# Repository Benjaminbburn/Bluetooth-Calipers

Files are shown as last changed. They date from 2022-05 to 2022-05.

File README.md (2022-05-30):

# Bluetooth-Calipers

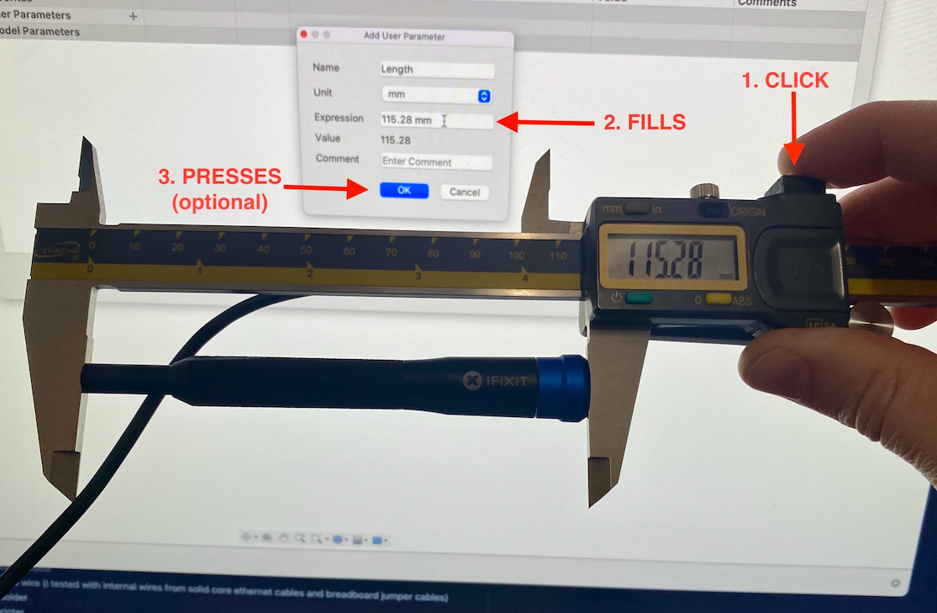
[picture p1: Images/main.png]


### Sends caliper data to connected bluetooth device when button is pressed.

---

The goal of this project was to recreate the functionality of [Mitutoyo's bluetooth U-WAVE](https://www2.mitutoyo.co.jp/eng/products/keisokusystem/wireless.html) using inexpensive hardware (total cost, excluding calipers, ~$15).

I ended up using USB for power since I am always near my computer when using this and did not want to manage a battery. There is no reason a 3.3v battery could not be added to make it fully wireless. Bluetooth was chosen to send data since many ESP32's are not able to act as a HID (i.e. cannot act as keyboard/mouse). 

Supports two types of button presses: 
1. **Short press**: Data is sent without pressing the return key (used when you want to modify the value)
2. **Long press**: Data is sent and the enter key is pressed (used when the value does not need to be modified)

---

Includes custom 3D files (.STEP, .3mf, and .STL) that provide a right angle connector for the connector and button as well as a case for the ESP32. I have included .3mf files with best support and print settings. 

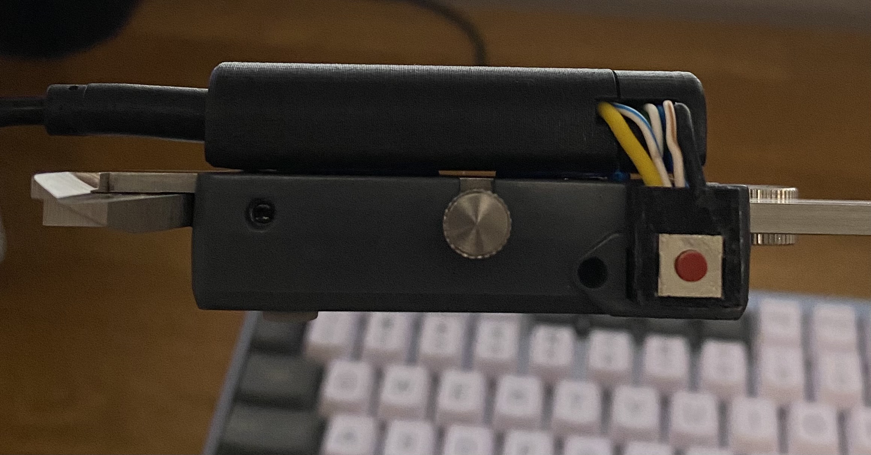
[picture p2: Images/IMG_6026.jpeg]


I have only tested with iGaging calipers that have a 5-pin data port. This should also work with Mitutoyo devices or other iGaging devices with a 5-pin data port.  

---

## Required Hardware
1. ESP32 - I used [this development board from amazon](https://www.amazon.com/HiLetgo-ESP-WROOM-32-Development-Microcontroller-Integrated/dp/B0718T232Z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)
2. Button - I used a 6mm x 6mm x 3.1mm button [from this kit on amazon](https://www.amazon.com/gp/product/B07LCBLB8N/ref=ppx_yo_dt_b_asin_title_o08_s00?ie=UTF8&psc=1)
3. 1 2N2222 Transistor 
4. 1 100k ohm resistor
5. Solid core wire (I tested with internal wires from solid core ethernet cables and breadboard jumper cables)
6. Wire/solder
7. 3D printer

---

## Build Guide

### Prepare the connector 

 1. Print "Caliper Data Port Connector - 5 pin". I found TPU worked the best. 
 2. Feel solid core wire as shows in the image below. Once all 5 wire are fed through, I used some super glue to hold them in place but it is not needed. 
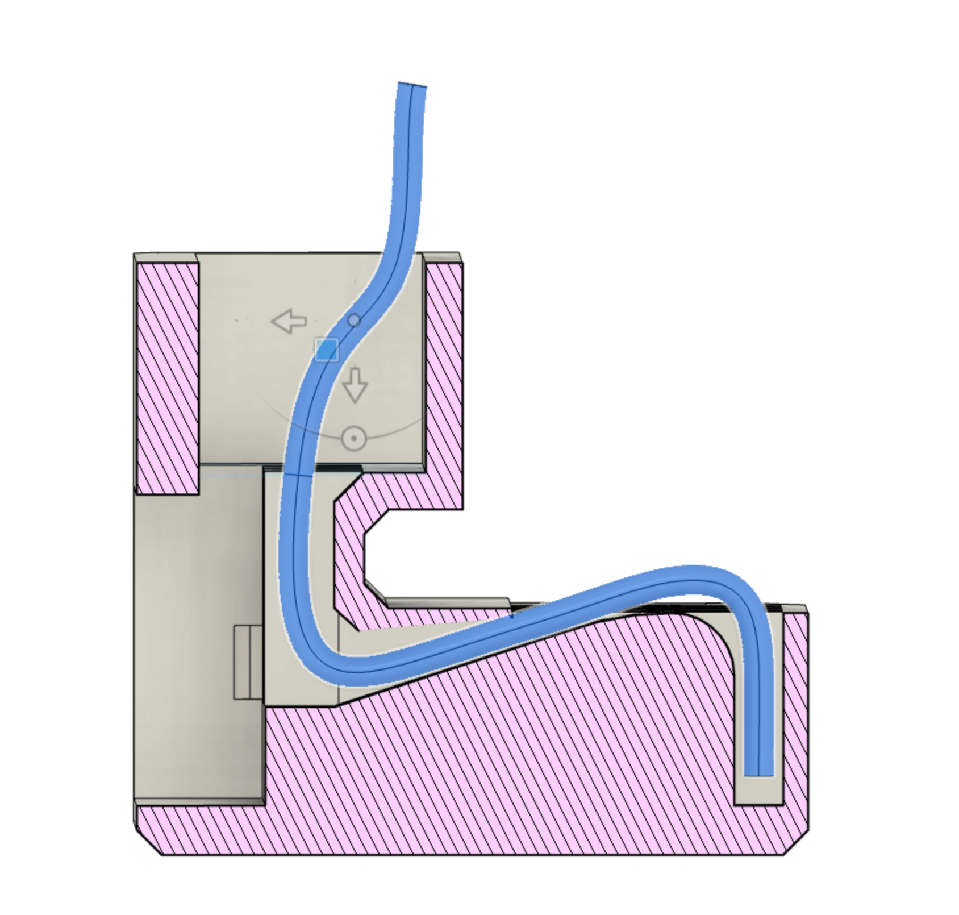
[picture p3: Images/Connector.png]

 3. Solder wires to the button and insert it in the square hole on the top of the connector piece, first feeding through the wires. 

### Making Connections

NOTE: PINS ARE EASY TO GET MIXED UP. 

Pins, as originally documented, from RIGHT to LEFT on calipers:
  1. GND - Ground 
  2. DATA - Measured data
  3. CK - Clock
  4. NA - No Connection
  5. REQ - Request

Since they were originally documented goings from RIGHT to LEFT when looking AT them on the calipers, their orientation flips for the image below (i.e. pin 1 on the LEFT and pin 5 on the RIGHT)



#### Soldering Steps

  0. De-solder any pins on the board. 
  1. Solder one button wire to pin 5 on the ESP32 and the other button wire to a ground pin on the ESP32.
  2. Solder GND (pin 1) from the connector to a ground pin on the ESP32.
  3. Solder the 100k ohm resister to the middle pin of the 2N2222 transistor.
  4. Solder the other end of the resistor to pin 2 on the ESP32.
  5. Solder the emitter pin on the 2N2222 transistor (right pin when flat side is facing you) to a ground pin on the ESP32.
  6. Solder collector pin on the 2N2222 transistor (left pin when flat side is facing you) to pin 5 on the connector.
  7. Solder DATA (pin 2) from the connector to pin 4 on the ESP32.
  8. Solder CLK (pin 3) from the connector to pin 0 on the ESP32.
  9. Solder the REQ (pin 5) from the connect to pin 2 on the ESP32

### Finishing up

1. Flash code using platformIO or Arduino IDE
2. Move everything into the case and connect connector to data port
3. Attach case to back of calipers (velcro, blu-tak, glue, VHB Tape, etc. all seem to work well)
4. When plugged in for the first time, connect to bluetooth device named "ESP32 Keyboard"

Once connected, used either the short or long press to send data to your connected device. 

---
## External Sources

Number 1 was used heavily for diagrams and base code (useful when you want to constantly return a value via USB without a button press). 

Number 2 has additional schematics and links to documenting provided by Mitutoyo 

1. https://www.instructables.com/Interfacing-a-Digital-Micrometer-to-a-Microcontrol/
2. https://github.com/Roger-random/mitutoyo

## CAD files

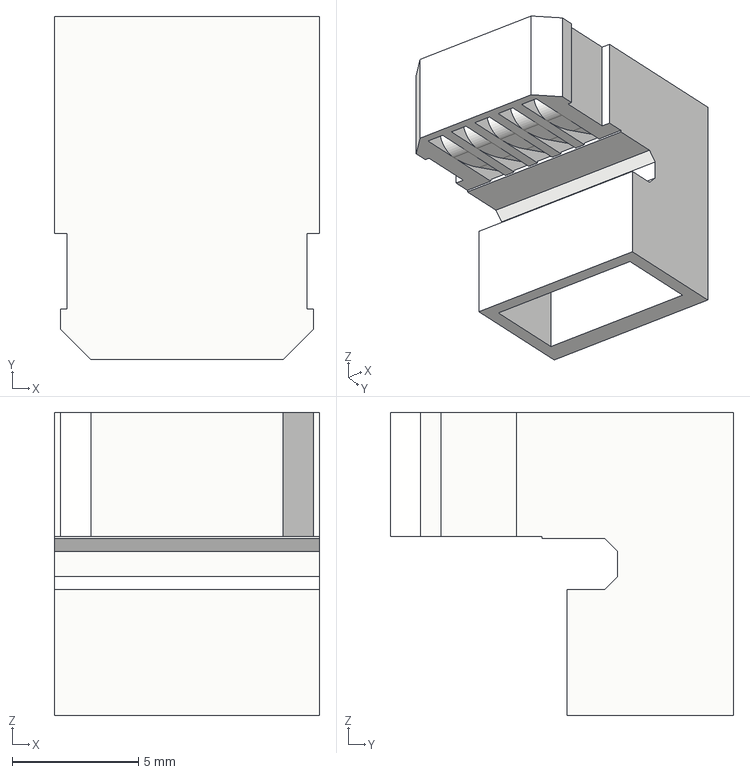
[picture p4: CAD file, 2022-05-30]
Design Files/STEPs/Caliper Data Port Connector - 5 pin.step
10.5 x 13.6 x 12.0 mm

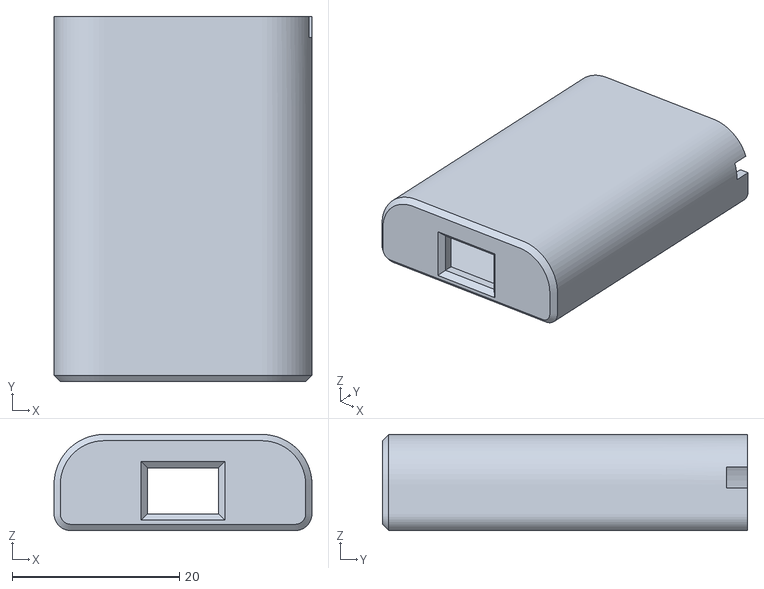
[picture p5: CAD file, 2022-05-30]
Design Files/STLs/Caliper ESP32 Case - Body.stl
30.8 x 43.6 x 11.5

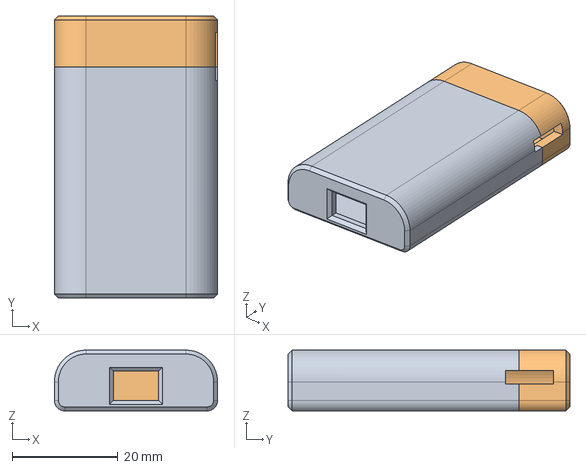
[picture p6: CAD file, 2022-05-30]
Design Files/STEPs/Caliper ESP32 Case.step
30.8 x 53.3 x 11.5 mm

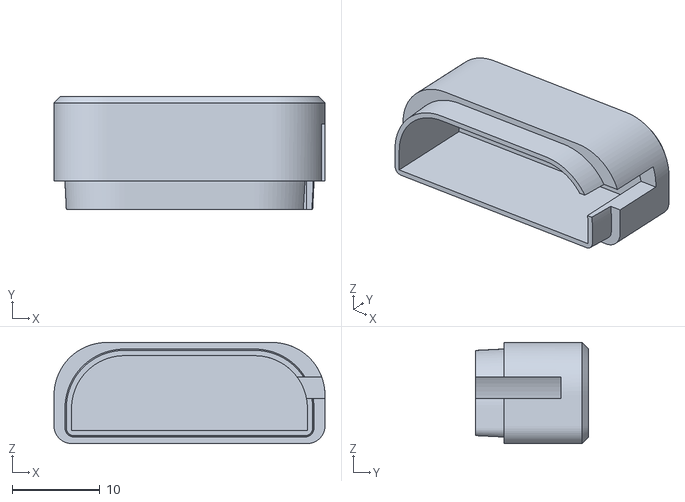
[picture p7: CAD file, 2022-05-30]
Design Files/STLs/Caliper ESP32 Case - Lid.stl
30.8 x 12.9 x 11.5

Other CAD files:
Design Files/3mfs/Caliper Data Port Connector - 5 pin.3mf
Design Files/3mfs/Caliper ESP32 Case.3mf
Design Files/STLs/Caliper Data Port Connector - 5 pin.stl

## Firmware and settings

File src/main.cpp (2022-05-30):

// Adapted from: 
// 1. https://www.instructables.com/id/Interfacing-a-Digital-Micrometer-to-a-Microcontrol/
// 2. https://github.com/Roger-random/mitutoyo

#include <Arduino.h>
#include <BleKeyboard.h>  //used to send keystrokes to connected device
#include <Bounce2.h>      //used to manage button behavior

// Pins, from RIGHT to LEFT on calipers
// 1. GND - Ground
// 2. DATA - Measured data
// 3. CK - Clock
// 4. NA - No Connection
// 5. REQ - Request 

int dat = 4; //Arduino pin for Data line, connects directly to SPC port pin 2 (DATA)
int clk = 0; //Arduino pin for Clock line, connects directly to SPC port pin 3 (~CLK)
int req = 2; //Arduino pin for REQ line, drives transistor to ground SPC port pin 5 (~REQ)

int btn = 5; //esp32 pin for button

int i = 0;  //used to count digits from calipers
int j = 0;  //used to count bits in each digit
int k = 0;  //value of the bit

int sign = 0;  //default value used to track if value is positive or negative
int decimal;   //determines where decimal is placed on returned value
float dpp;      //decimal point position, number used as denominator that moves decimal to correct position
int units;     //value that determines mm's or in's

byte mydata[14];    //stores data from calipers
String value_str;   //string representation of the value
long value_int;     //was an int, could not measure over 32mm
float value;         //value as a float, used to position decimal
String units_str;   //unit, as a string
String output_val;  //output value, as a string

int alreadyReported = 0;  //tracks if a value has already been returned, prevents duplicate values when long pressing 

BleKeyboard bleKeyboard;   //creates a bleKeyboard object
Bounce bounce = Bounce();  //creates a bounce object
String get_data();         //inits the get_data function

void setup() {
  Serial.begin(115200);  //starts the serial monitor, useful for debugging
  
  pinMode(req, OUTPUT);              //sets req pin to output
  pinMode(clk, INPUT_PULLUP);        //sets clk to input_pullup
  pinMode(dat, INPUT_PULLUP);        //sets dat to input pullup
  digitalWrite(req,LOW);             // set req to low by default
  bounce.attach(btn, INPUT_PULLUP);  //sets button to input_pullup
  bounce.interval(1);                //sets the bounce interval to 1ms
  
  bleKeyboard.begin();  //init the blekeyboard
}

void loop() {
  if(bleKeyboard.isConnected()) {  //only checks button once bluetooth is connected
    
    bounce.update();  //checks button status
    int debouncedState = bounce.read();

    if (debouncedState == LOW && bounce.currentDuration() > 500 && alreadyReported == 0) {  //checks if button is pressed, has been held for 500ms, and a number has not been reported
      //Serial.println("Detected long press");  //DEBUG line
      String caliper_val = get_data();          //gets data from calipers
      bleKeyboard.print(caliper_val);           //types reported value to connected device
      bleKeyboard.write(KEY_RETURN);            //hits enter on connected device
      alreadyReported = 1;                      //ensures value is only reported once per press

    } else if (bounce.rose() && alreadyReported == 1) {   //checks if the button is released and a number is reported
      //Serial.println("Reset values after long press");  //DEBUG line
      alreadyReported = 0;                                //resets the variable that prevents multiple reports from long presses

    } else if (bounce.rose() && alreadyReported == 0) {  //checks if button is released and a number has not been reported
      //Serial.println("Detected short press");          //DEBUG line
      String caliper_val = get_data();                   //gets data from calipers
      bleKeyboard.print(caliper_val);                    //types reported values to connected device
    }
  }
}

String get_data() {
  //Serial.print("REQ value when button is pressed: "); Serial.println(digitalRead(req));  //DEBUG line
  digitalWrite(req, HIGH); //requests the current value from calipers  
  //Serial.print("REQ value after being set to high: "); Serial.println(digitalRead(req)); //DEBUG line
  
  //Following section parses the data stream reported from the calipers to generate a value. 
  //See supporting docs: https://www.instructables.com/Interfacing-a-Digital-Micrometer-to-a-Microcontrol/ 
  //Step 3: Reading the Mitutoyo Output -> #2 Data format
  for( i = 0; i < 13; i++ ) {  //data consists of 13 digits
    k = 0;
    for (j = 0; j < 4; j++) {  //each digit consists of 4 bits.
      //Serial.println("waiting for clock: ");  //DEBUG line
      while( digitalRead(clk) == LOW) {  // hold until clock is high
        //Serial.println("waiting for clock to not be LOW");  //DEBUG line
        } 
      while( digitalRead(clk) == HIGH) {  // hold until clock is low
        //Serial.println("waiting for clock to not be HIGH");  //DEBUG line
        } 
      
    bitWrite(k, j, (digitalRead(dat) & 0x1)); //Each clock cycle, we record the bits on the data line
    }
  
  mydata[i] = k;
  }
  
  sign = mydata[4];      //this digit tells us if data is positive or negative
  value_str = String(mydata[5]) + String(mydata[6]) + String(mydata[7]) + String(mydata[8] + String(mydata[9] + String(mydata[10]))) ; //this combines the data digits to give the raw number value reported
  decimal = mydata[11];  //this digit gives the location of the decimal
  units = mydata[12];    //this digit gives the units (mm or in)

  //following if statements are used to move our decimal to the correct place in the reported value
  if (decimal == 0) dpp = 1.0;
  if (decimal == 1) dpp = 10.0;
  if (decimal == 2) dpp = 100.0;
  if (decimal == 3) dpp = 1000.0;
  if (decimal == 4) dpp = 10000.0;
  if (decimal == 5) dpp = 100000.0;

  value_int = value_str.toInt();       //converts the value to an integer
  value = value_int / dpp;             //gets value with decimal place
  value_str = String(value, decimal);  //converts back to a string for reporting
  
  // following if statements add appropriate units depending on units value
  if (units == 0) units_str = " mm";  
  if (units == 1) units_str = " in";  

  // following if statements apply appropriate sign depending on sign value
  if (sign == 0) {
    output_val = "";
    //Serial.print(value,decimal); Serial.println(units_str);  //DEBUG line
  }
  if (sign == 8) {
    output_val = "-";
    //Serial.print("-"); Serial.print(value,decimal); Serial.println(units_str);  //DEBUG line
  }
  
  output_val.concat(value_str);  //combines the sign with the value
  output_val.concat(units_str);  //combines result from above with the units
  
  digitalWrite(req,LOW);  //resets request line

  return(output_val);    //returns the output value as a string
}

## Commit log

2022-05-30 init commit - 3d files
    [Caliper Data Port Connector - 5 pin.3mf, Caliper Data Port Connector - 5 pin.step, Caliper Data Port Connector - 5 pin.stl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]
2022-05-30 Added connector image
2022-05-30 ESP32 wiring added
